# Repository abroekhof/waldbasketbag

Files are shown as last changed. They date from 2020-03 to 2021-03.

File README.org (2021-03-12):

* MYOG Wald 137 Basket Bag Pattern                                     :MYOG:
[[./img/bike.jpg/]]

Wald baskets come in a few sizes, the most popular for basketpacking being 137 and 139. The 137 is smaller and fits better between drop bars.

** Pattern
A not-to-scale pattern is exported to [[./wald137bag.pdf]]. The panels are simple enough to measure out, rather than printing and tracing.

The pattern ([[./wald137bag.dxf]]) was created using [[https://www.qcad.org/][QCAD]].

** Materials
- 1 yard rollable material for collar (I used VX21 X-Pac)
- 1 yard abrasion-resistant fabric for area touching basket (I used 1000D Cordura)
- 10' 1" webbing
- 2 Double Adjust Side Release Buckles (if you don't mind not being able to buckle the top together to form a handle, you can use single-adjust)
- (Optional) 1 yard lining material (I used 1.9 oz PU coated Ripstop Nylon)
- (Optional) 1/8" closed-cell foam for padding
- (Optional) 1" grosgrain ribbon for edge binding
- (Optional) 2 plastic swivel snap hooks

** Notes
- Seam allowances are 3/8"

** Instructions
*** Make the basket portion
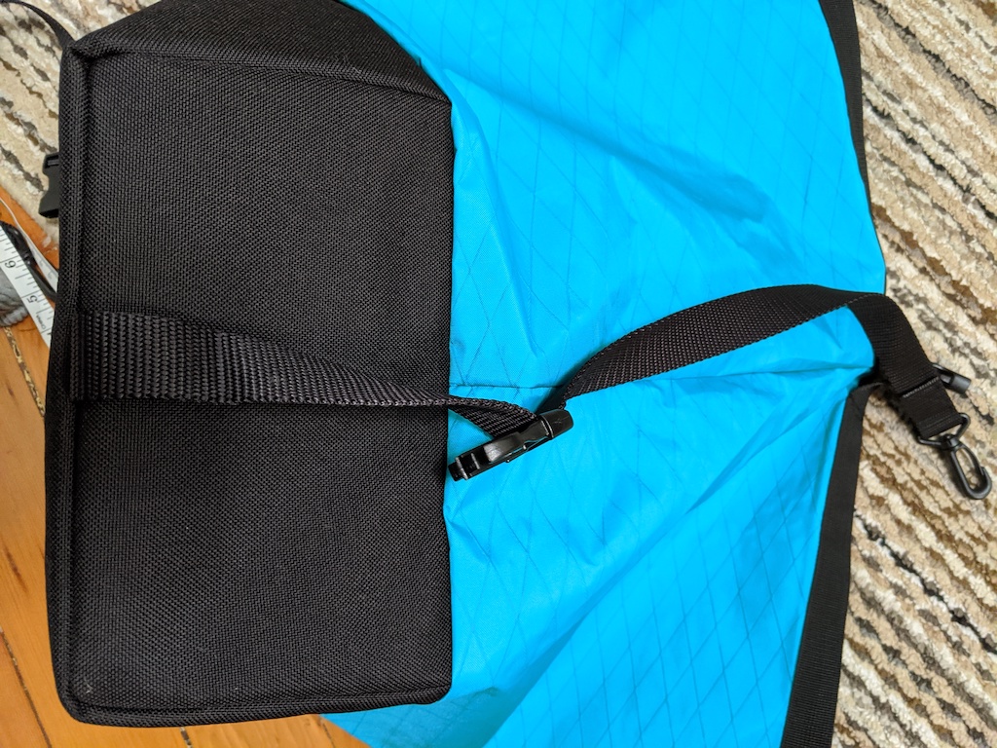
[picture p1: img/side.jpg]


1. Cut out the fabric pieces. You should have 2 side pieces and 1 bottom piece in both the outer and lining fabrics
2. If you are using padding, cut out side and bottom pieces shrunk 1" smaller than the fabric pieces. This will prevent the foam from being sewn into the seam allowance.
3. Sew the lining to outer pieces, wrong-side to wrong-side, less than 3/8" from the edge, leaving one side open to insert the foam, then sewing closed
4. Pin a 2' piece of webbing at the midpoint of the bottom seam on the right-side. This webbing will feed out and around the basket to hold the bag in place. Then sew the side piece to the bottom piece. Repeat on the other side.
5. Bind the seams with grosgrain ribbon

*** Make the collar
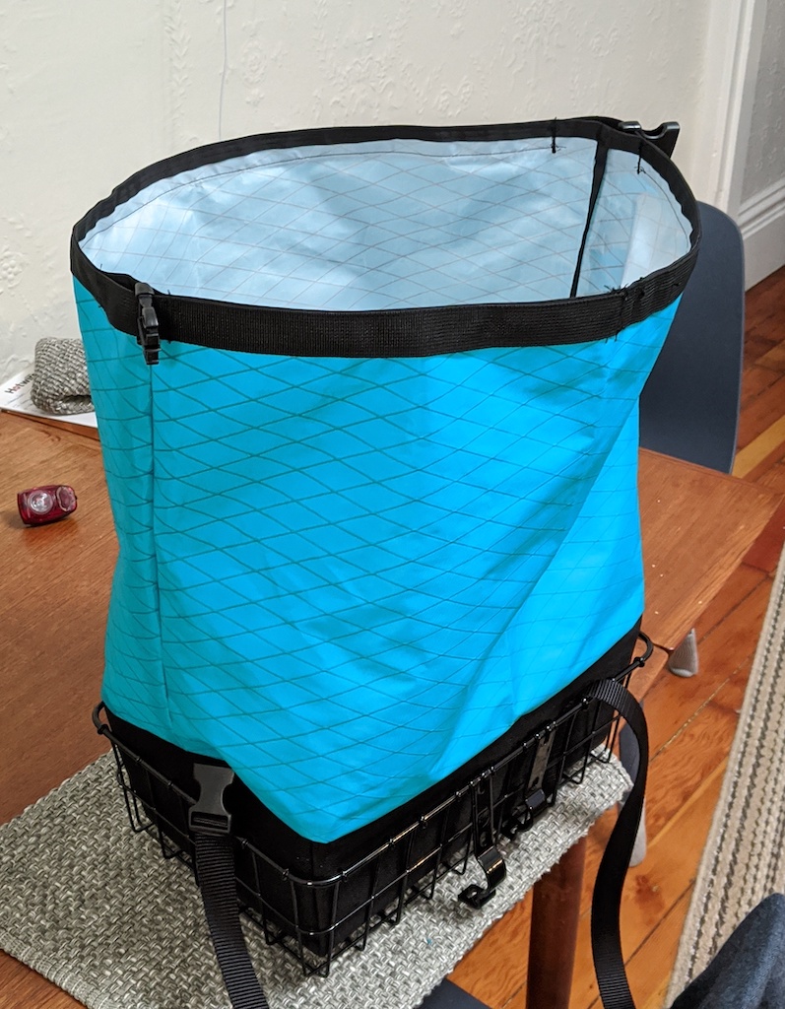
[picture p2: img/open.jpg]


1. Wrong-side to wrong-side, sew the collar fabric together on the shorter edges to form a tube
2. Bind the seams with grosgrain ribbon

*** Attach the collar to the basket portion
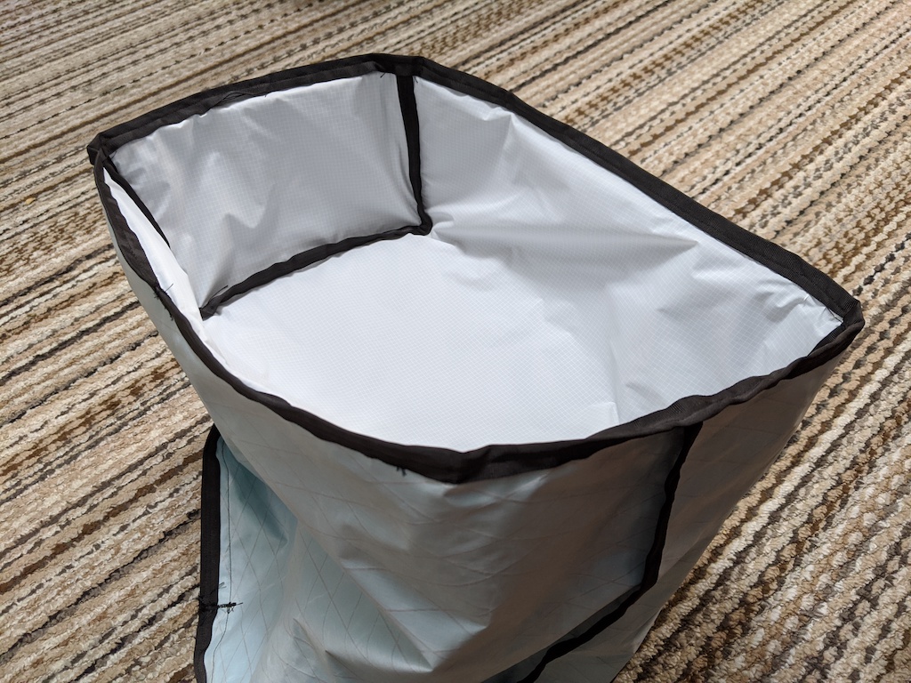
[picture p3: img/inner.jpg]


1. With the collar inside-out, place the basket portion inside the collar, so that the top of the basket portion is flush with one edge of the collar,  aligning the seams of the collar with the midpoints of the side panels
2. Sew around the top of the basket portion to attach the collar
3. Bind the seam with grosgrain ribbon

*** Finishing touches
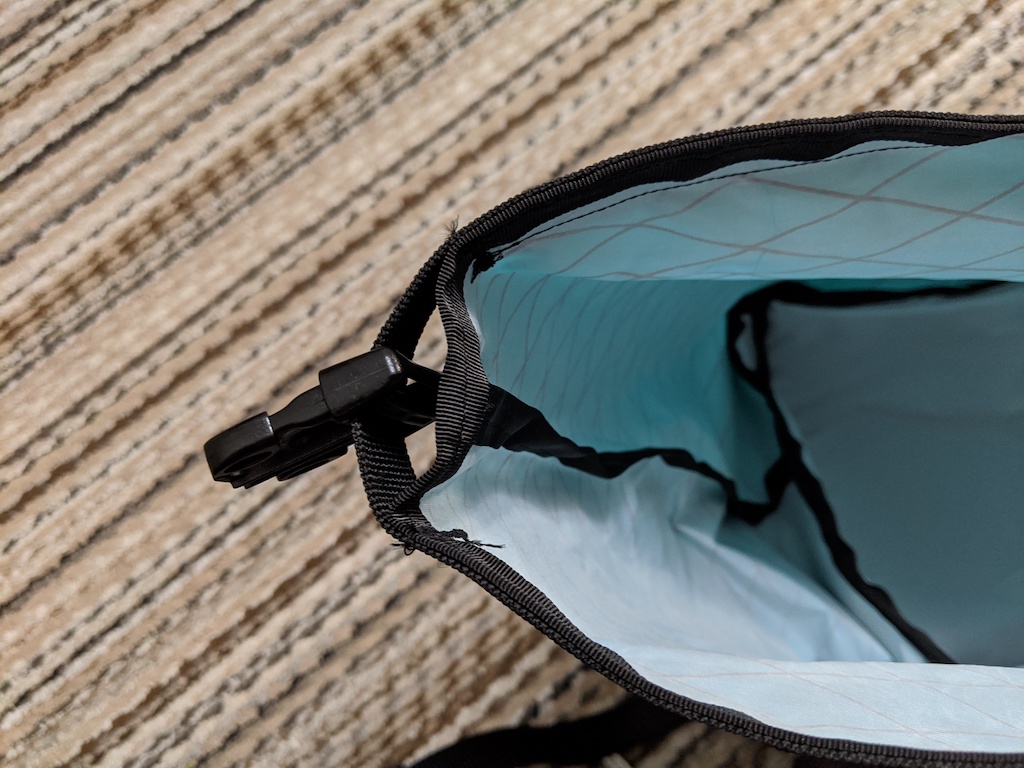
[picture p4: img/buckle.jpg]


1. Bind the top of the collar with ribbon
2. Starting mid-way between the collar seams, start sewing webbing around the perimeter of the collar, stopping 1" before the first seam. Thread on a female buckle, and resume sewing 1" after the seam. Repeat when you reach the second seam, but with the male buckle.
3. Bar-tack on both sides of each buckle and where the two ends of the webbing meet
4. Attach the remaining buckles to the loose straps and sew the ends (I sewed on swivel hooks to attach to the basket).

** Contributing
Feel free to open a pull request!

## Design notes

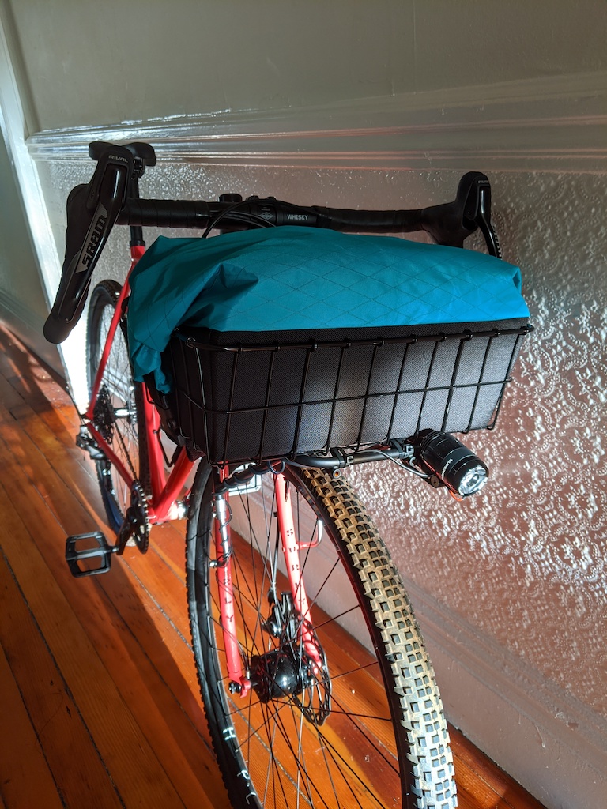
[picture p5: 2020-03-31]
img/bike.jpg

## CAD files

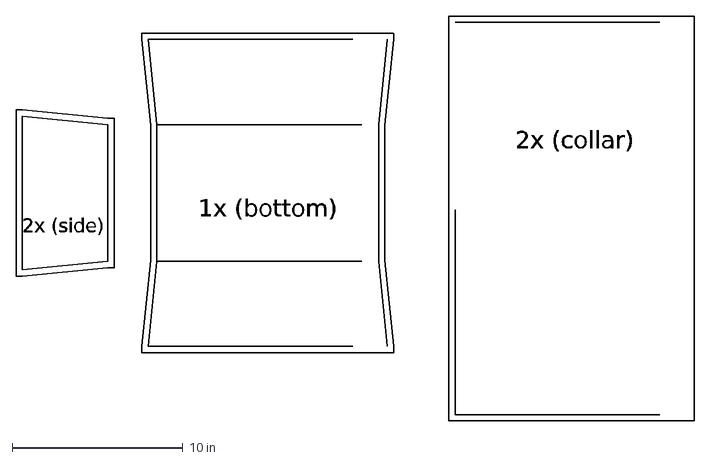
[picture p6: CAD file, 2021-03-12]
wald137bag.dxf
2x (collar)
2x (side)
1x (bottom)

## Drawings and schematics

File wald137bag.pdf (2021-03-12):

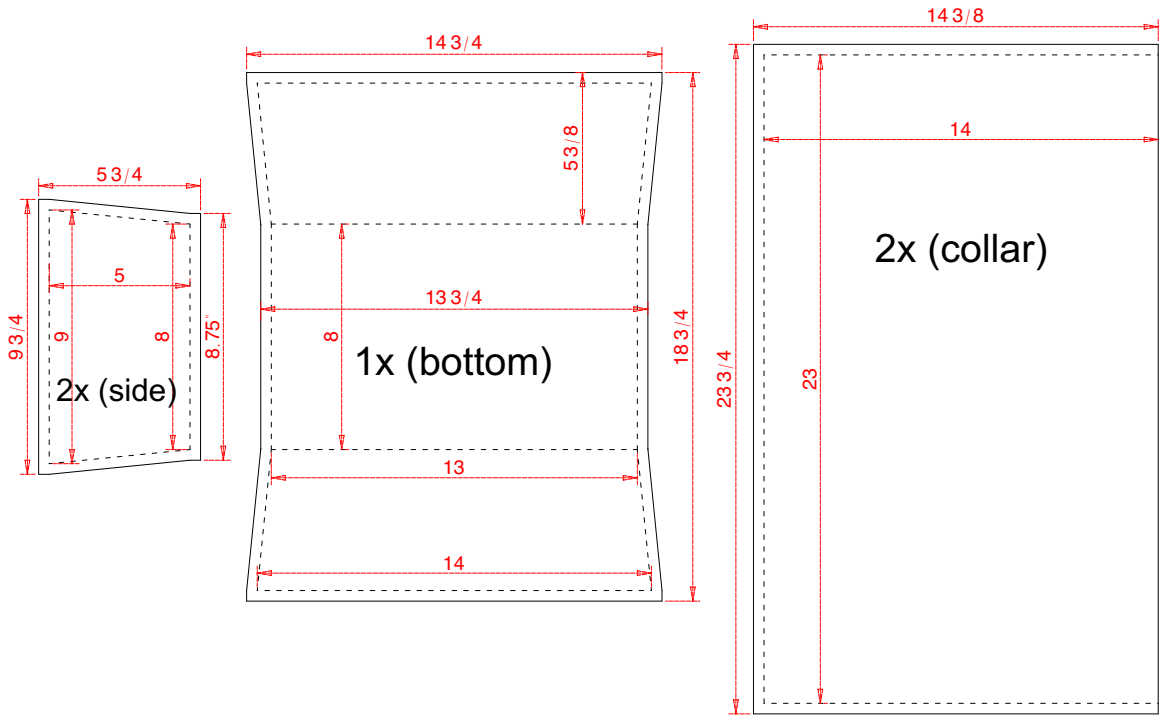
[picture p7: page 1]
2x (collar); 2x (side); 1x (bottom)

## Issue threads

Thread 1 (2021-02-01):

long dimension for collar pieces is wrong in PDF

snicker, 2021-02-01:
cooked one of these up in the past week as my first sewing project, thank you for doing all the work of measuring and writing out the process!!

I have not checked the DXF, but the long dimension for the 2x collar pieces seems off. I modified to 2'-0 1/4" and still had a slight bit of slack (This is with 1/8" foam and a 3/8" seam allowance)

The basket section should have a closed perimeter dimension of  `(1'-2" * 2) + ( 9" * 2 ) = 3'-10" (46")` when finished with a 3/8" seam allowance.

However, the current dimensions for the collars read `2'-2.75"`, which results in a "tube" perimeter dimension of `4'-4" (52")` with a 3/8" seam. This leaves 6 inches of slack in the tube that must be folded in.

As a novice and not knowing how much slack I needed to provide, I modified the collar long dimension to `2'-0 1/4"` resulting in a closed tube perimeter of 47". Even this additional inch had to be folded in around the corners, and I believe I could've used less material.

completed bag attached! I love it!
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

limnoted, 2021-02-01:
I’m currently finishing up a bag using this pattern and I noticed the same thing re. the collar pieces being too long.
I calculated that each piece could be 60.4 cm long including seam allowances.
However, I’d be hesitant to recommend that people cut it that short, given small individual differences between bags.
What I did was cut the pieces to the recommended length, then pinned the pieces to the bottom of the bag & marked where the appropriate overlap would occur.
Then I unpinned the upper & trimmed to the appropriate length.
On the one hand my approach wastes two ~10 cm strips of fabric (relatively expensive x-pac in my case), but on the other hand it avoids cutting the pieces too short & wasting big pieces of fabric.

When I’m done my bag I’ll post some suggested edits to the instructions, re. the approach described above & recommended collar piece dimensions. Overall it has been a really fun experience and is my first sewing project! The basket portion fits like a glove into the 137. I’ve made a couple of other small changes like adding interior sleeve pockets on the sides, and d-rings in the corners for a shoulder belt. I’ve also made a metric version of your CAD drawings. I’ll post all of these together to Git. I really wanted to make a zippered pass through into the main bag at the base, but sadly it’s beyond my skill for now 😊

Ted

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

abroekhof, 2021-03-12:
Hey all, apologies for not responding earlier—apparently I don't get email notifications for GitHub, and haven't checked here for a while. Let me take a look at what you've all found and I'll get back to you.

Thanks!

abroekhof, 2021-03-12:
Fixed in 165dba0fb4bb8f1230684b154ff010319ab40a85

I'm not sure what happened here, but I've updated the collar width to be 23", plus 3/8" on either side for seam allowance. This should produce a 46" collar, as you calculated above @snicker.

By the way, bag looks great, where did you get that fabric?

snicker, 2021-03-12:
@abroekhof https://www.spoonflower.com/ is where I found it- seems to be a cool site where anyone can upload a pattern and they will print to a fabric of your choice. not exactly cheap, but the options are endless. This was a denim fabric in and out, I was considering waxing it for protection, but I'm seeing how my stitching holds up with commuter rides around town. Thanks again for the pattern!!

Closed 2021-03-12.

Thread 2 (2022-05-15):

Good job!

aocole, 2022-05-15:
This isn't a real issue, it's just my way of saying thanks for this pattern. I messed around with the straps and maybe made some bad choices, but we'll see!

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

Good job on the pattern and thanks for sharing it!

aocole, 2022-05-15:
No action required

abroekhof, 2022-05-15:
@aocole nice work, looks awesome! That LED strip is pretty cool too.

Yeah, I've been thinking about alternative strap configs, since it does get a bit tiresome always having to thread the long straps through the rack. I think other brands use velcro to secure it, which might be interesting.

Closed 2022-05-15.

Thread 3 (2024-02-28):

Loved this pattern!  Made a few modifications

subdavis, 2024-02-28:
I really enjoyed making this bag, thank you for publishing! I'm really happy with the materials I picked, all from Rockywoods (except the pellon)

* Inner structure: Pellon 1/8inch sew-in foam for the body
* Pink body: Cordura 1000D for the outer basket bag
* Liner and collar: Challenge Recycled Bag Cloth (RBC) - Coated 400D Fabric w/ Eco Friendly C0 DWR
* Nexus GTSR Buckles
* 1 Inch Grosgrain Ribbon, Mil-Spec Style 5038

## Modifications

The main thing I wanted to clean up was the look of the enclosure.  I didn't love how the fabric spiraled around the webbing near the buckle and ran over the side of the basket.  I don't expect to overload this thing, so I sacrificed just a bit of the top end capacity to have it fold like a paper bag at the top.

* I left the right and left side un-stitched
* On the left and right, where there's 9 inches of collar at the top, I only gave 7.5 of webbing so that the bag would close properly when almost empty.
* In order to encourage the bag to do the paper-bag fold, I sewed some pinch seams on all 4 edges.  I looked at a lot of basket bags and saw this on [the wizard works alekazam](https://www.wizard.works/shop/sale-all/sale-bags/alakazam-basket-bag/).

| | |
|----|----|
| 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 | 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 |
| 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 | 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 |

abroekhof, 2024-03-02:
Nice improvements! Glad the pattern was useful!

If you have any interest in updating the instructions with your improvements, would be happy to merge them.

dmenchaca, 2024-05-09:
@subdavis thanks for sharing your modifications.

When you said:
> - On the left and right, where there's 9 inches of collar at the top, I only gave 7.5 of webbing so that the bag would close properly when almost empty.

Do you mean to say that instead of the 14 3/8" which was in the original pattern you made your collar only 9" high?

Thanks!

abroekhof, 2024-05-14:
@dmenchaca I think @subdavis is talking about the 9" side rather than the height.

dmenchaca, 2024-05-15:
@abroekhof yup I see what you mean, thanks!

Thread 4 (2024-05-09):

Issue with seam allowances

dmenchaca, 2024-05-09:
Hi @abroekhof,

Thanks for creating this pattern.

I see on the instructions you mention:

> Seam allowances are 3/8”

Yet on the pdf for the sides and bottom I see a seam allowance of 3/4 inch and for the collar 3/8 inch.

Which seam allowance is right? My guess is that I may not be reading the pdf right.

Thanks!

abroekhof, 2024-05-09:
Hey Diego,
You are indeed reading the PDF wrong! :smile: (but I also didn't make it super clear). The 3/4" you're seeing is the full width of the panel, which includes two 3/8" allowances for the total of 3/4".

Let me know if that makes sense!

-Alex

abroekhof, 2024-05-09:
No worries, stoked you're using the pattern.

What do you mean by double allowance? So for example, the side panel is 5 inches tall, or it will be once it's sewn into the bag. On both sides of that panel, there are 3/8" seam allowances that will be hidden once the bag is done.
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
So the full height of the panel is 5+3/8+3/8 = 5 3/4".

The collar only has a seam allowance on one side because only one edge is sewn. The other edge is rolled and attached to the webbing.

dmenchaca, 2024-05-09:
I just realised how silly my question was 😂.  I totally got it now.

Thanks a ton! I'll share a pictures here once I'm done.

abroekhof, 2024-05-09:
No worries! It also took me a while to get a hang of all these extra measurements, it's a lot to keep track of.

Good luck, looking forward to the pics!

dmenchaca, 2024-05-09:
@abroekhof for higher weatherproofness I'm debating whether to bind the seams with grosgrain ribbon or a PU seam sealing tape.

Have you ever noticed water making it's way through the seams?

abroekhof, 2024-05-09:
I'm in Bay Area, and don't ride in the rain extensively, but the times I have, I have not noticed much leakage through grosgrain bound seams.

dmenchaca, 2024-05-09:
Gotcha, thanks!

Closed 2024-05-09.
